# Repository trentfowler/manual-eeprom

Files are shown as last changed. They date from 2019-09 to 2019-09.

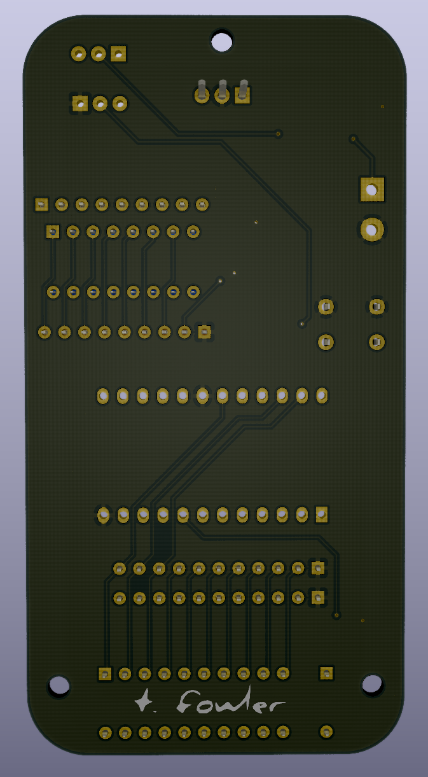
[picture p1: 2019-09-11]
img/rev1_final/3d_back_sivs64r.png

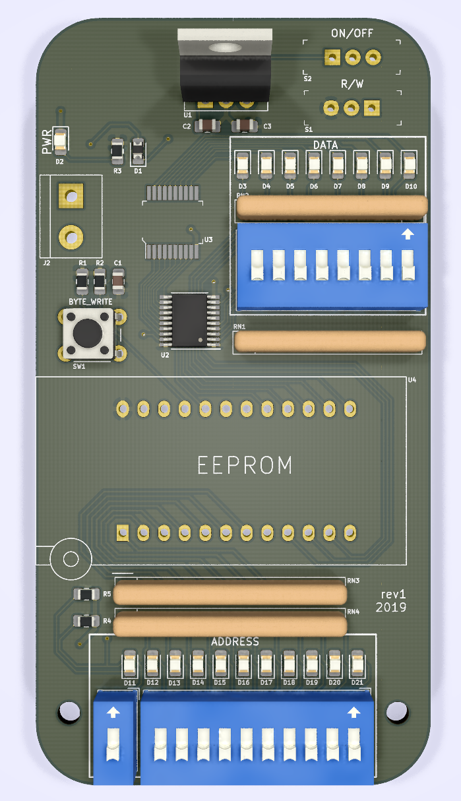
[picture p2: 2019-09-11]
img/rev1_final/3d_front_2rXFVzv.png

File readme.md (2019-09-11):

# Manual EEPROM programmer

**Description:** KiCad project files for manual EEPROM programmer pcb that uses dip switches to program the the AT28C16 EEPROM

AT28C16 - http://cva.stanford.edu/classes/cs99s/datasheets/at28c16.pdf

**Rev 1 final:**

schematic

no fill

front

back

3d-front

3d-back

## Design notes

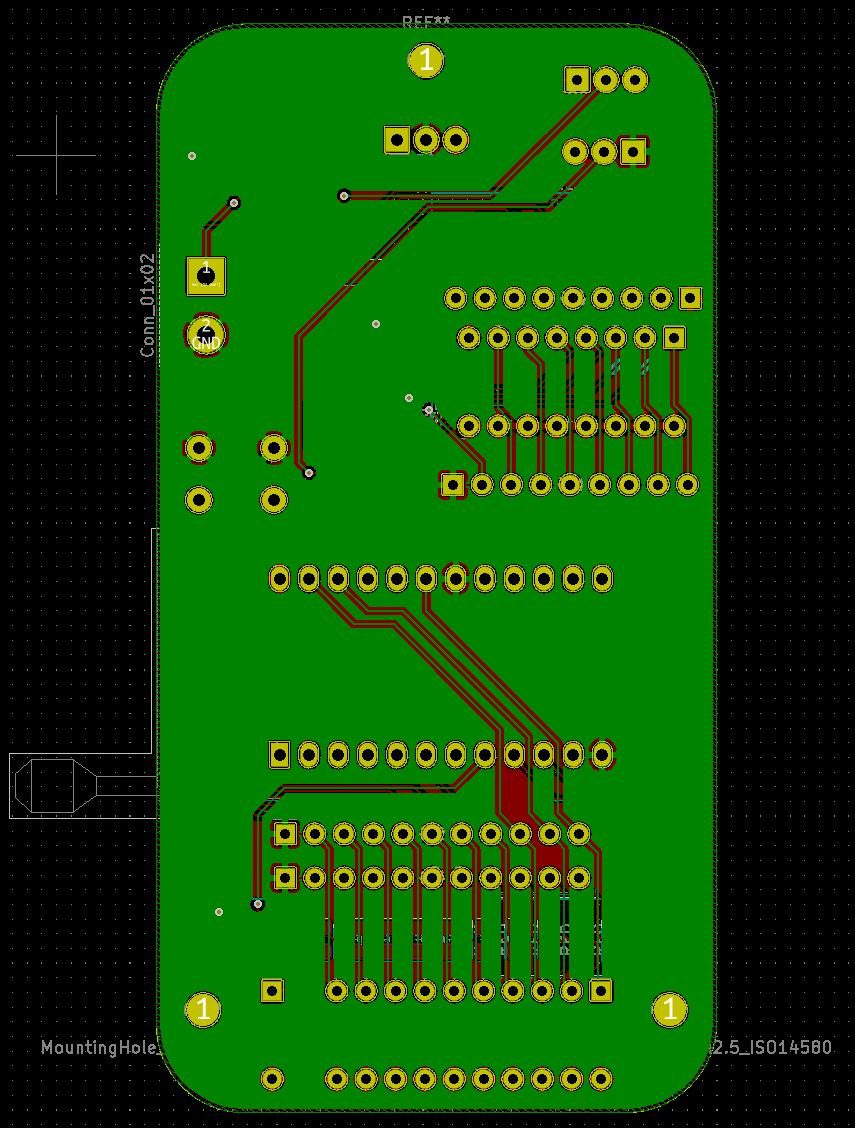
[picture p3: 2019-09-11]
img/rev1_final/back_zvdU0BY.png

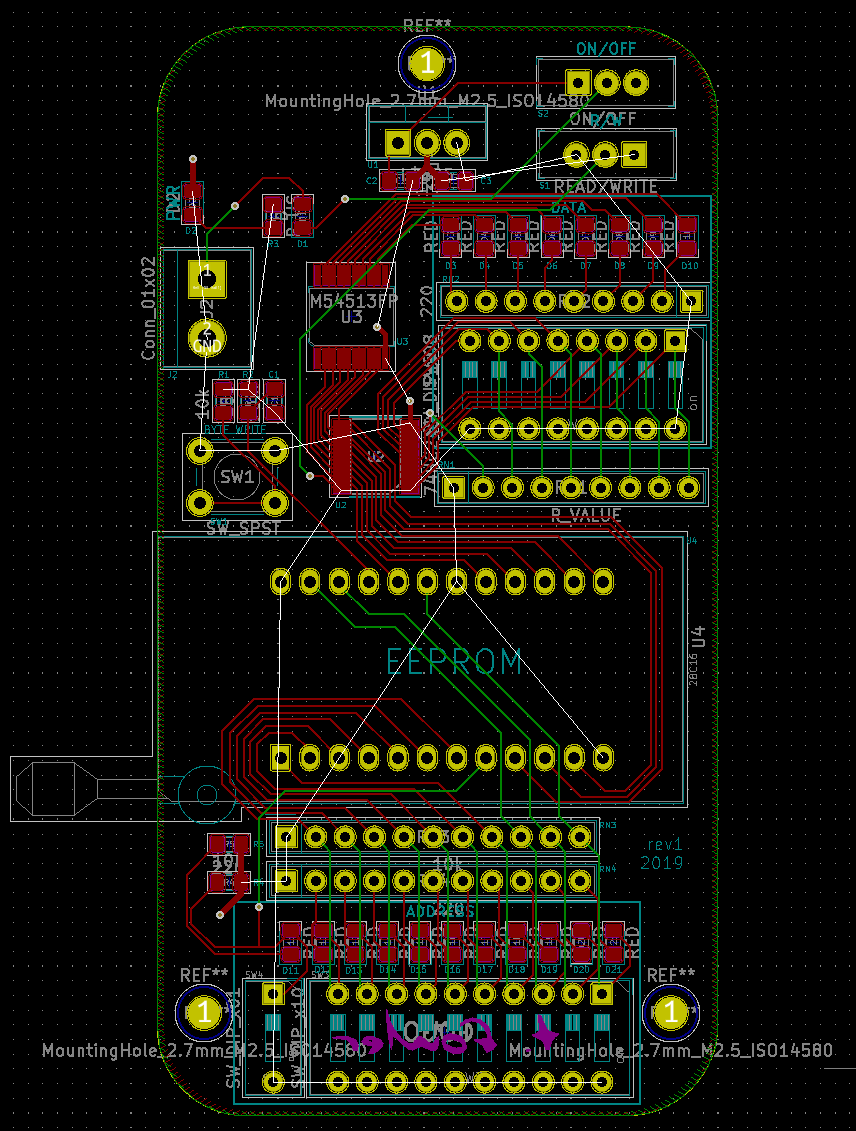
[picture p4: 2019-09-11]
img/rev1_final/nofill_zsWwC9.png

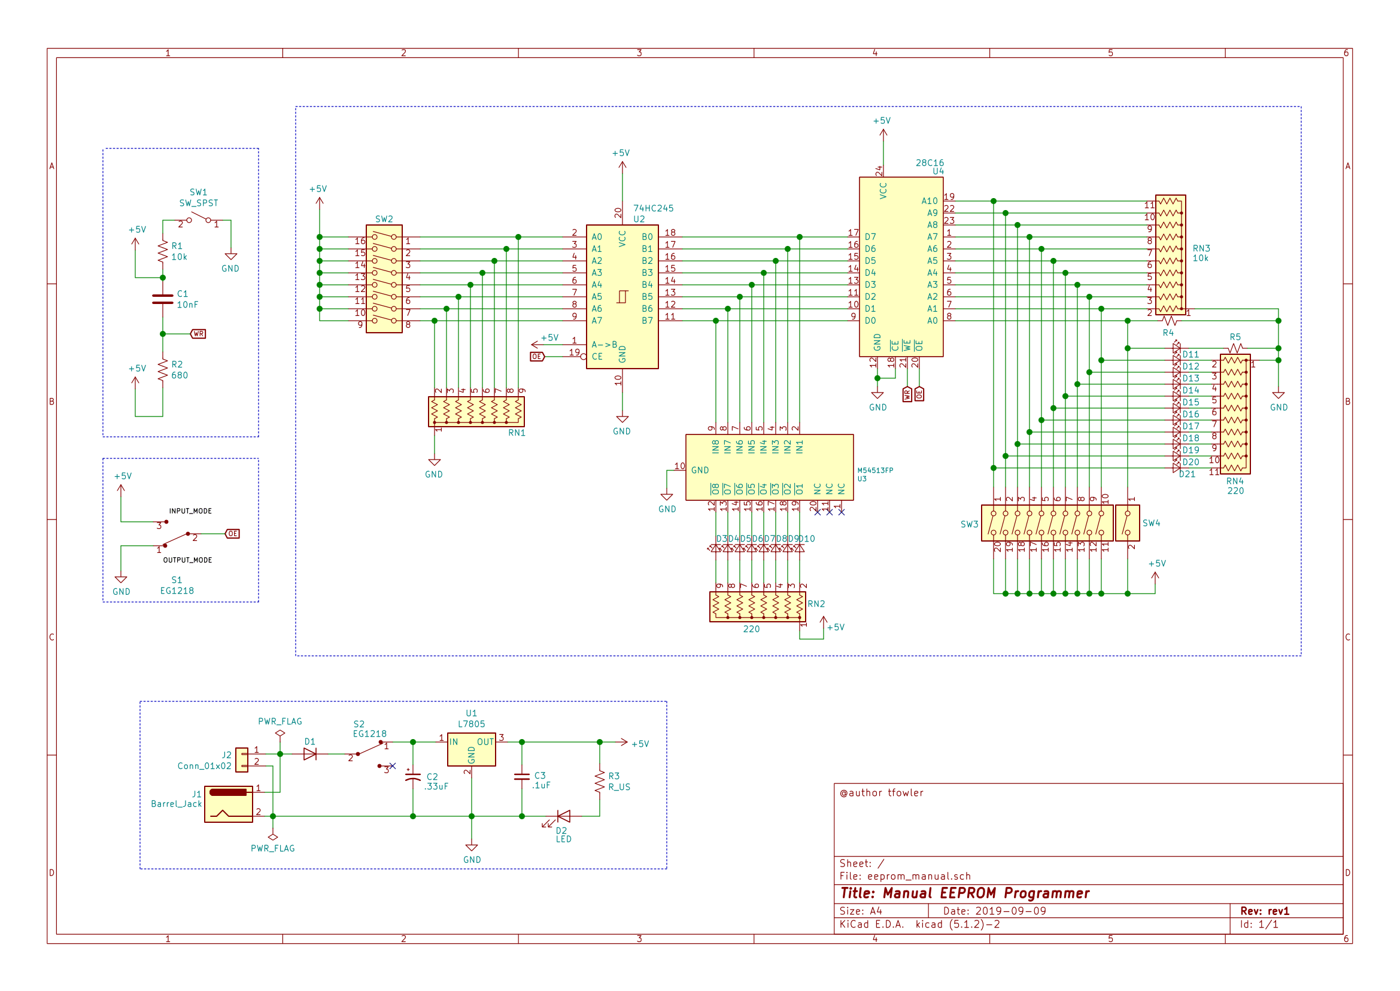
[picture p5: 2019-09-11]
img/rev1_final/eeprom_sch_WRPkA4P.png

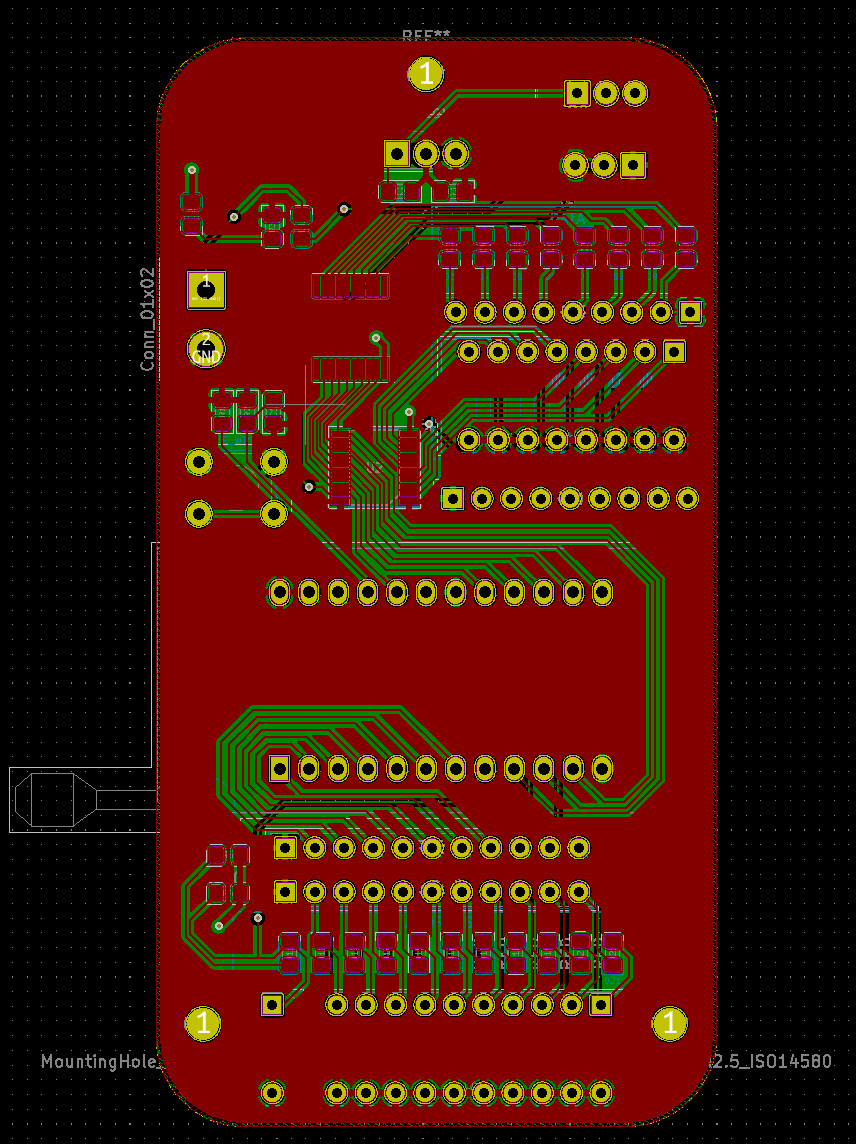
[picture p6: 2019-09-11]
img/rev1_final/front_35fpuWl.png

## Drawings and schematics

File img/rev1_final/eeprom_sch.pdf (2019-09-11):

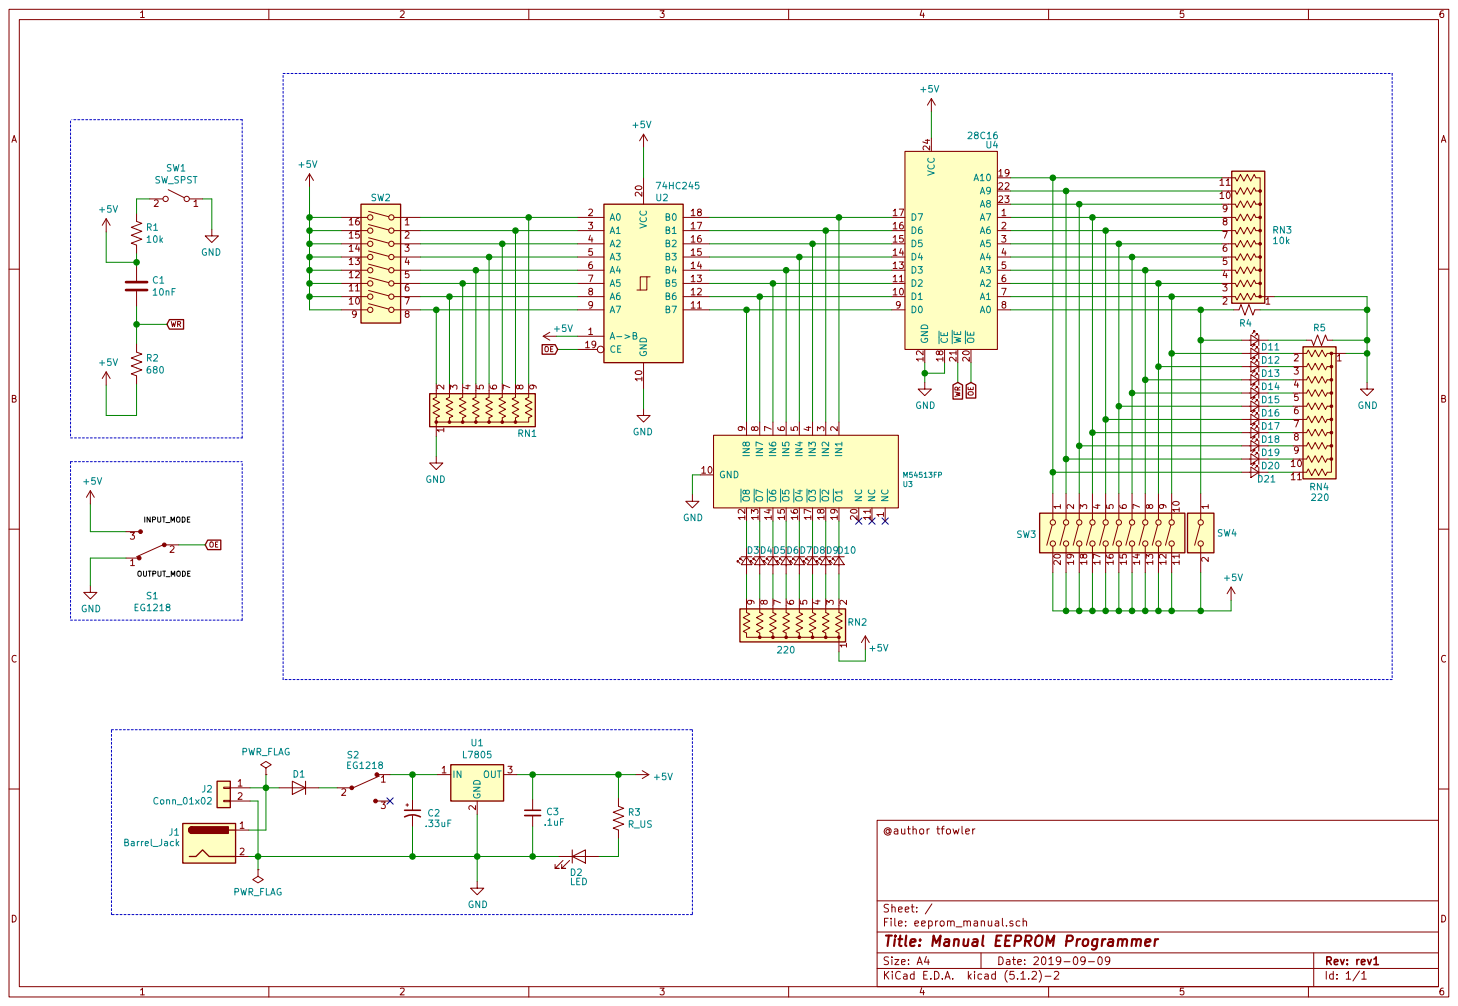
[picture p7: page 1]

File: eeprom_manual.sch Sheet: / @author tfowler

Id: 1/1 Title: Manual EEPROM Programmer

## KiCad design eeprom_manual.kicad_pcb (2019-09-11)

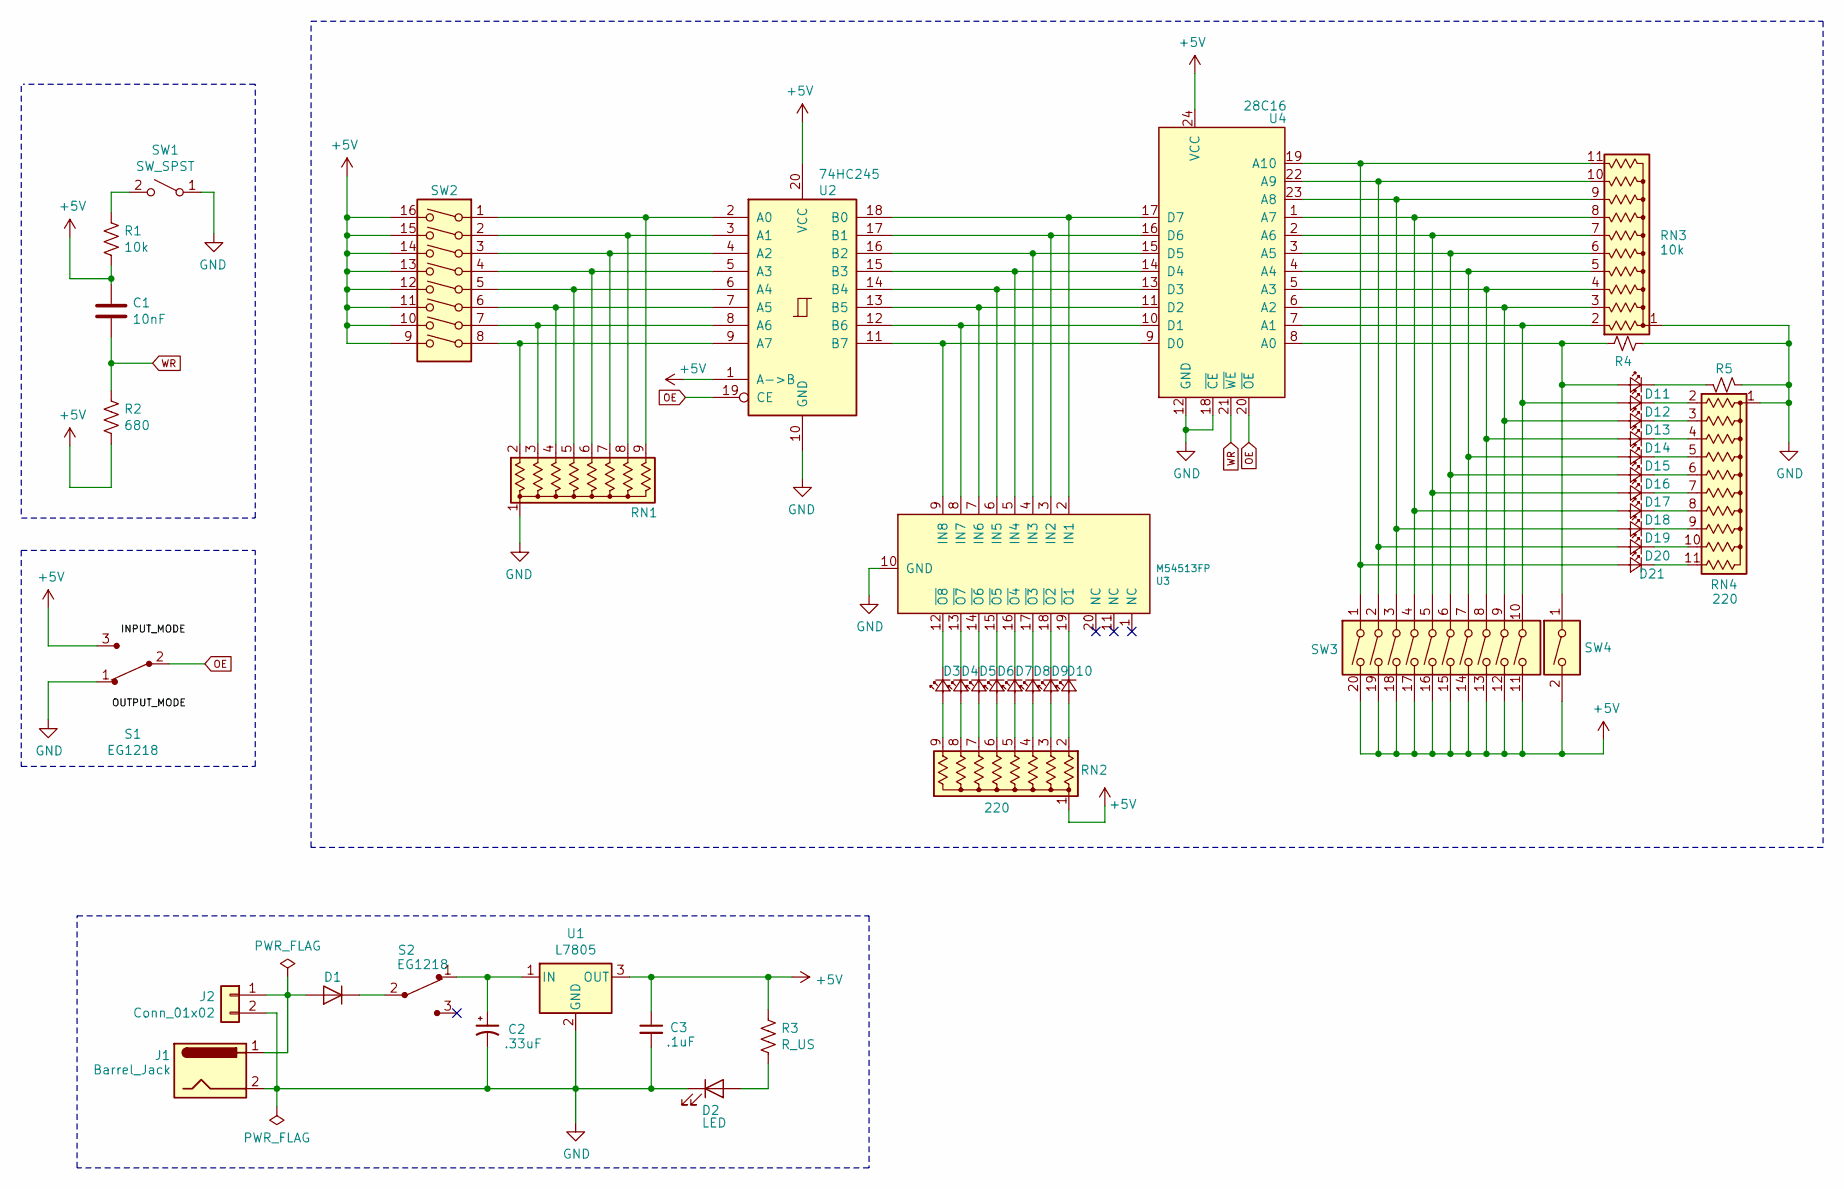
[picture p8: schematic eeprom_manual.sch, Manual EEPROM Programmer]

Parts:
C1: 10nF; C_0805_2012Metric_Pad1.15x1.40mm_HandSolder
C2: .33uF; C_0805_2012Metric_Pad1.15x1.40mm_HandSolder
C3: .1uF; C_0805_2012Metric_Pad1.15x1.40mm_HandSolder
D1: D; D_0805_2012Metric_Pad1.15x1.40mm_HandSolder
D2: LED; LED_0805_2012Metric_Pad1.15x1.40mm_HandSolder
D3, D4, D5, D6, D7, D8, D9, D10, D11, D12, D13, D14, D15, D16, D17, D18, D19, D20, D21: RED; LED_0805_2012Metric_Pad1.15x1.40mm_HandSolder
J1: Barrel_Jack; Barrel_Jack_5.5mmODx2.1mmID_PJ-202A
J2: Conn_01x02; TerminalBlock_bornier-2_P5.08mm
R1, R4: 10k; R_0805_2012Metric_Pad1.15x1.40mm_HandSolder
R2: 680; R_0805_2012Metric_Pad1.15x1.40mm_HandSolder
R3: R_US; R_0805_2012Metric_Pad1.15x1.40mm_HandSolder
R5: 220; R_0805_2012Metric_Pad1.15x1.40mm_HandSolder
RN1: R_VALUE; R_Array_SIP9
RN2: 220; R_Array_SIP9
RN3: 10k; R_Array_SIP11
RN4: 220; R_Array_SIP11
S1, S2: EG1218; Switch_Slide_11.6x4mm_EG1218; MPN EG1218; Digi-Key_PN EG1903-ND
SW1: SW_SPST; SW_PUSH_6mm
SW2: SW_DIP_x08; SW_DIP_SPSTx08_Slide_9.78x22.5mm_W7.62mm_P2.54mm
SW3: SW_DIP_x10; SW_DIP_SPSTx10_Slide_9.78x27.58mm_W7.62mm_P2.54mm
SW4: SW_DIP_x01; SW_DIP_SPSTx01_Slide_9.78x4.72mm_W7.62mm_P2.54mm
U1: L7805; TO-220-3_Vertical
U2: 74HC245; TSSOP-20_4.4x6.5mm_P0.65mm
U3: M54513FP; SSOP-20_W5.3mm
U4: 28C16; DIP_Socket-24_W11.9_W12.7_W15.24_W17.78_W18.5_3M_224-1275-0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

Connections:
+5V: C1.1, C3.1, R1.2, R2.2, R3.1, RN2.1 (common), S1.3, SW2.9, SW2.10, SW2.11, SW2.12, SW2.13, SW2.14, SW2.15, SW2.16, SW3.11, SW3.12, SW3.13, SW3.14, SW3.15, SW3.16, SW3.17, SW3.18, SW3.19, SW3.20, SW4.2, U1.3 (OUT), U2.1 (A->B), U2.20 (VCC), U4.24 (VCC)
GND: C2.2, C3.2, D2.1 (K), J1.2, J2.2, R4.1, R5.1, RN1.1 (common), RN3.1 (common), RN4.1 (common), S1.1, SW1.1 (A), U1.2 (GND), U2.10 (GND), U3.10 (GND), U4.12 (GND), U4.18 (~CE)
unnamed: C2.1, S2.1, U1.1 (IN)
unnamed: D1.1 (K), S2.2
unnamed: D1.2 (A), J1.1, J2.1
unnamed: D2.2 (A), R3.2
unnamed: D3.1 (K), U3.12 (~O8)
unnamed: D3.2 (A), RN2.9 (R8)
unnamed: D4.1 (K), U3.13 (~O7)
unnamed: D4.2 (A), RN2.8 (R7)
unnamed: D5.1 (K), U3.14 (~O6)
unnamed: D5.2 (A), RN2.7 (R6)
unnamed: D6.1 (K), U3.15 (~O5)
unnamed: D6.2 (A), RN2.6 (R5)
unnamed: D7.1 (K), U3.16 (~O4)
unnamed: D7.2 (A), RN2.5 (R4)
unnamed: D8.1 (K), U3.17 (~O3)
unnamed: D8.2 (A), RN2.4 (R3)
unnamed: D9.1 (K), U3.18 (~O2)
unnamed: D9.2 (A), RN2.3 (R2)
unnamed: D10.1 (K), U3.19 (~O1)
unnamed: D10.2 (A), RN2.2 (R1)
unnamed: D11.1 (K), R5.2
unnamed: D11.2 (A), R4.2, SW4.1, U4.8 (A0)
unnamed: D12.1 (K), RN4.2 (R1)
unnamed: D12.2 (A), RN3.2 (R1), SW3.10, U4.7 (A1)
unnamed: D13.1 (K), RN4.3 (R2)
unnamed: D13.2 (A), RN3.3 (R2), SW3.9, U4.6 (A2)
unnamed: D14.1 (K), RN4.4 (R3)
unnamed: D14.2 (A), RN3.4 (R3), SW3.8, U4.5 (A3)
unnamed: D15.1 (K), RN4.5 (R4)
unnamed: D15.2 (A), RN3.5 (R4), SW3.7, U4.4 (A4)
unnamed: D16.1 (K), RN4.6 (R5)
unnamed: D16.2 (A), RN3.6 (R5), SW3.6, U4.3 (A5)
unnamed: D17.1 (K), RN4.7 (R6)
unnamed: D17.2 (A), RN3.7 (R6), SW3.5, U4.2 (A6)
unnamed: D18.1 (K), RN4.8 (R7)
unnamed: D18.2 (A), RN3.8 (R7), SW3.4, U4.1 (A7)
unnamed: D19.1 (K), RN4.9 (R8)
unnamed: D19.2 (A), RN3.9 (R8), SW3.3, U4.23 (A8)
unnamed: D20.1 (K), RN4.10 (R9)
unnamed: D20.2 (A), RN3.10 (R9), SW3.2, U4.22 (A9)
unnamed: D21.1 (K), RN4.11 (R10)
unnamed: D21.2 (A), RN3.11 (R10), SW3.1, U4.19 (A10)
unnamed: R1.1, SW1.2 (B)
unnamed: RN1.2 (R1), SW2.8, U2.9 (A7)
unnamed: RN1.3 (R2), SW2.7, U2.8 (A6)
unnamed: RN1.4 (R3), SW2.6, U2.7 (A5)
unnamed: RN1.5 (R4), SW2.5, U2.6 (A4)
unnamed: RN1.6 (R5), SW2.4, U2.5 (A3)
unnamed: RN1.7 (R6), SW2.3, U2.4 (A2)
unnamed: RN1.8 (R7), SW2.2, U2.3 (A1)
unnamed: RN1.9 (R8), SW2.1, U2.2 (A0)
unnamed: U2.11 (B7), U3.9 (IN8), U4.9 (D0)
unnamed: U2.12 (B6), U3.8 (IN7), U4.10 (D1)
unnamed: U2.13 (B5), U3.7 (IN6), U4.11 (D2)
unnamed: U2.14 (B4), U3.6 (IN5), U4.13 (D3)
unnamed: U2.15 (B3), U3.5 (IN4), U4.14 (D4)
unnamed: U2.16 (B2), U3.4 (IN3), U4.15 (D5)
unnamed: U2.17 (B1), U3.3 (IN2), U4.16 (D6)
unnamed: U2.18 (B0), U3.2 (IN1), U4.17 (D7)
OE: S1.2, U2.19 (CE), U4.20 (~OE)
WR: C1.2, R2.1, U4.21 (~WE)

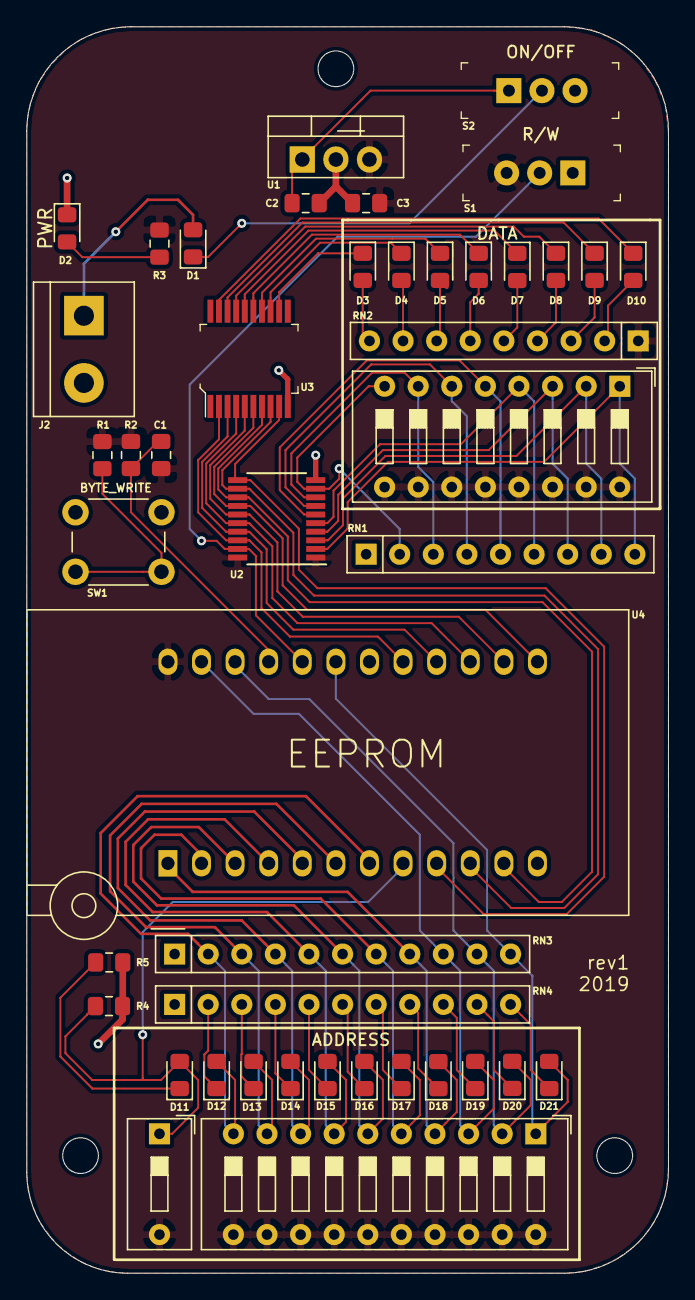
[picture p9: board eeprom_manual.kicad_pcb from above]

Board: 2 copper layers, 48.5 x 94.2 mm, 44 parts (0 on the bottom side), 63 nets.

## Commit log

2019-09-09 Assign footprints (initial)
    [eeprom_manual.sch]
2019-09-09 Update footprints
    - Generate net list
    [eeprom_manual.sch]
2019-09-10 Created pcbnew component layout
    [eeprom_manual.sch]
2019-09-10 Added traces to pcb
    - pcbnew component layout adjustments
    [eeprom_manual.kicad_pcb]
2019-09-11 Add silkscreen labels, Clean up traces
    [eeprom_manual.kicad_pcb]
2019-09-11 rev.1 final (add silkscreen, gerbers, spread traces)
    - Generated gerbers and drill file
    - custom bitmap logo created, assigned component footprint, placed on back
    of pcb
    - Updated readme with rev.1 final pictures
    - Spread out traces and tweaked clearances
    [eeprom_manual-B_Cu.gbr, eeprom_manual-B_Mask.gbr, eeprom_manual-B_SilkS.gbr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]
2019-09-11 Remove old schematic
2019-09-11 Sync kicad working files with project after program save/exit
    [eeprom_manual.kicad_pcb]
